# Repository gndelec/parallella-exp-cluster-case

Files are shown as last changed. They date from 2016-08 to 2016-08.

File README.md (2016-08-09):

# Parallella Experimental Cluster Case Kit

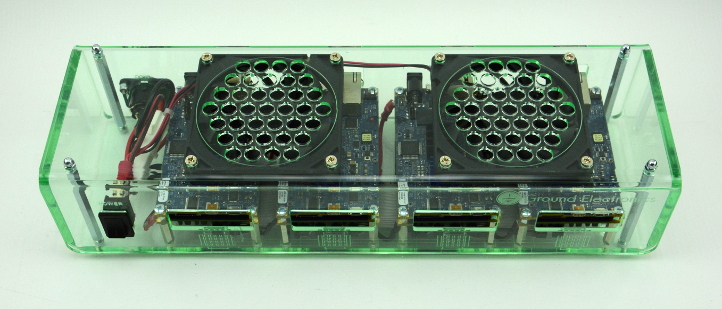
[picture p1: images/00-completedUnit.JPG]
A completed PACK-02 case


The PACK-02 kit is a simple but elegant case based on the "[sick of beige](http://dangerousprototypes.com/docs/Sick_of_Beige_basic_case_v1)" design and is intended for experimentation with the Parallella platform, along with multiple Porcupine breakout boards and eLink cables. It can be bought from [Ground Electronics](http://groundelectronics.com).

## Repository contents

The case design is provided in the following formats:

* Inkscape SVG (source)
* PDF
* DXF

The top cover is laser cut from 3mm glass look acrylic.
The base is laser cut from 5mm glass look acrylic.

## Bill of materials

In addition to the acrylic parts the PACK-02 kit contains:

| Qty | Item |
| --- | --- |
|  2  | 80mm  slimline fan |
|  1  | Rectangular rocker switch |
|  1  | Panel mount XLR socket |
|  4  | M3 x 60mm steel hex standoffs, M-F  |
|  16 | M3 x 20mm  steel hex standoffs, F-F |
|  16 | M3 x 5mm steel hex standoffs, M-F |
|  16 | M3 x 5mm steel machine screw |
|  4  | M3 x 8mm steel machine screw |
|  16 | M3 x 12mm nylon machine screw |
|  2  | M3 x 10mm countersunk steel machine screw |
|  2  | M3 nyloc nut |
|  8  | M5 x 12mm self tapping steel screw  |
|  4  | M3 dome nut |
|  4  | Self-adhesive rubber bumper |
|  1  | Small cable tie |
|  3  | Red jumper wire with ring terminals |
|  3  | Black jumper wire with ring terminals |
|  1  | Two-pin power connector with flying leads |
|  14 | M3 washer |
|  3  | Short ribbon cable w/30 pin connectors |
|  3  | Long ribbon cable w/30 pin connectors |
|  1  | High quality 5V, 8A power supply |

This kit is intended for between 2-4 Parallella boards, as well as Porcupine breakout boards (not included in the kit):

| Qty | Item |
| --- | --- |
| 2-4 | Parallella board |
| 2-4 | Porcupine breakout board |

## Assembly

Completed PACK-02

1 Remove the protective plastic from the acrylic panels.The top come pre-assembled with fans, switch and XLR socket in place.

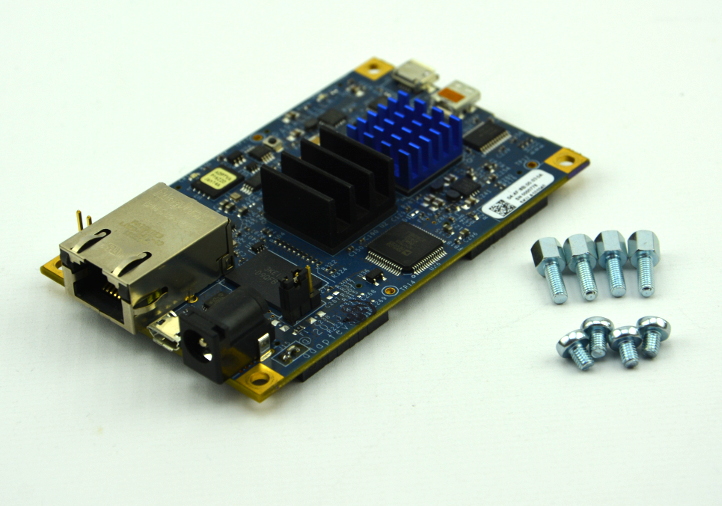
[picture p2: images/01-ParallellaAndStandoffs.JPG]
Parallella and standoffs


2 Start with a Parallella, 4x M3x5mm standoffs and 4x M3x5mm machine screws.

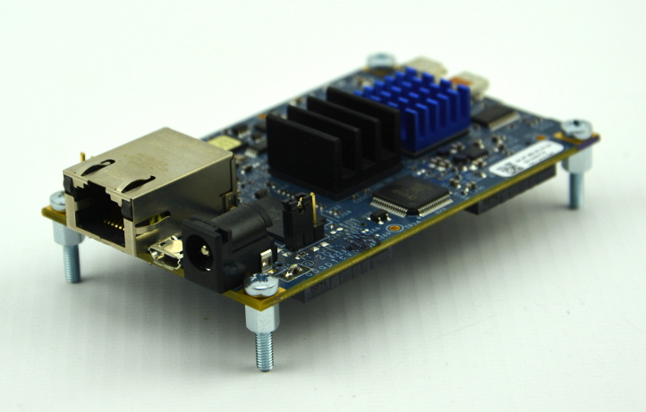
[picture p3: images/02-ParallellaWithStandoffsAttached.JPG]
Adding standoffs


3 Add the standoffs and screws as shown, and repeat for all Parallellas.

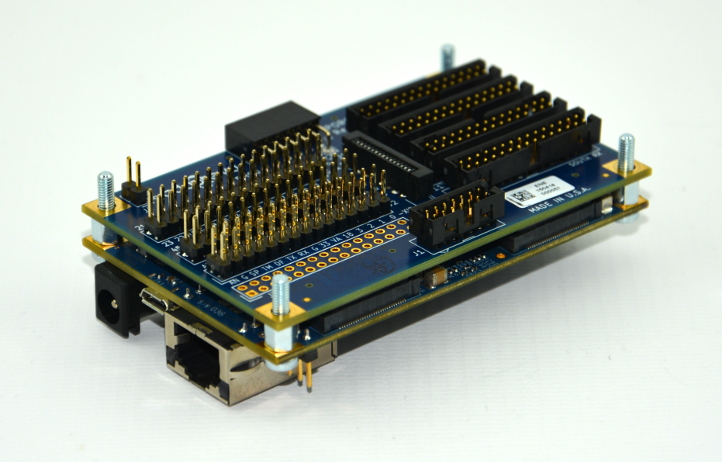
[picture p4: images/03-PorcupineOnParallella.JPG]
Adding Porcupine


4 Add the Porcupine breakout board, taking care that it is correctly oriented, and the high-density connectors are aligned before pushing together. Repeat for all Parallellas.

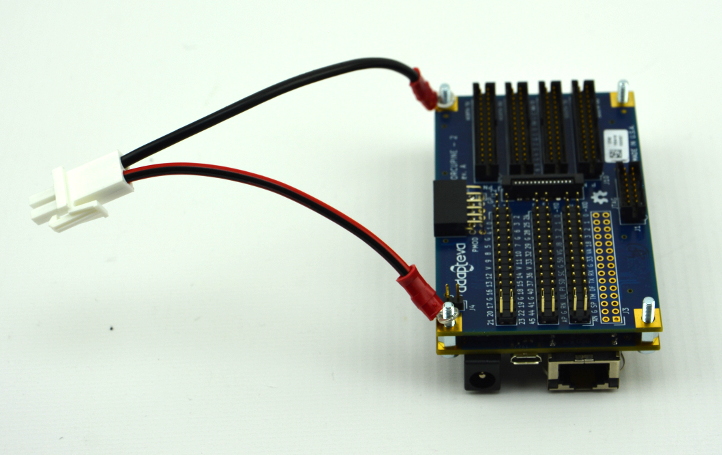
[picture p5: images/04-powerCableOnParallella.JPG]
Adding power cable


5 Add the main power cable to the first Parallella.

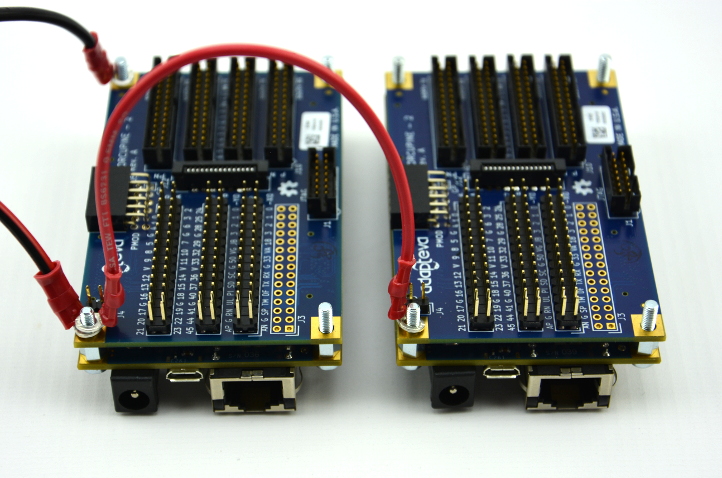
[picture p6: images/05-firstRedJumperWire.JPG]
Adding red jumper wire


6 Add the first red jumper wire as shown, between two Parallella boards. Take care to add to the correct threaded posts.

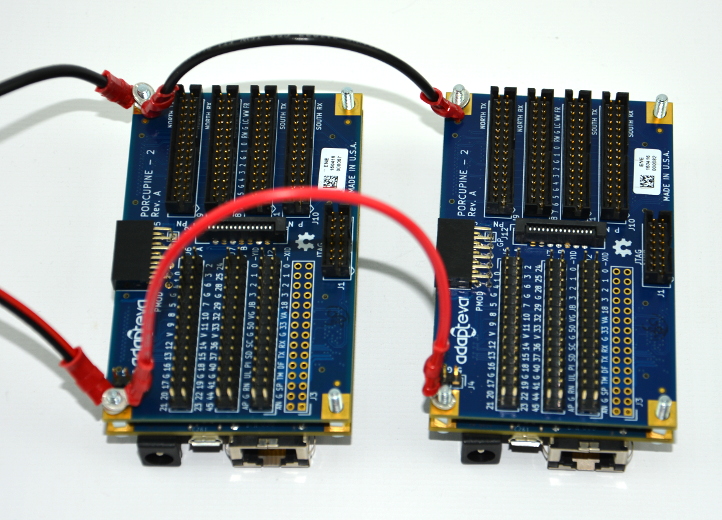
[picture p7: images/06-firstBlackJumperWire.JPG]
Adding black jumper wire


7 Add the first black jumper wire as shown, again taking care that to add it to the correct threaded posts.

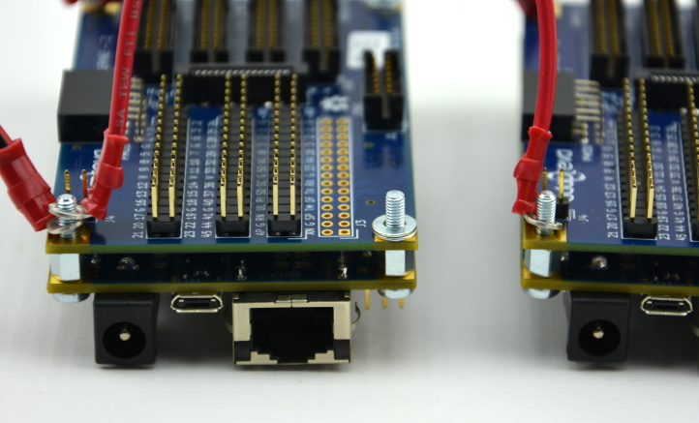
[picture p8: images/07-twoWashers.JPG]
Adding M3 washers


8 Add 4x M3 washers to the first Parallella, 2 to each unoccupied post, to match up with those occupied by the ring terminals.

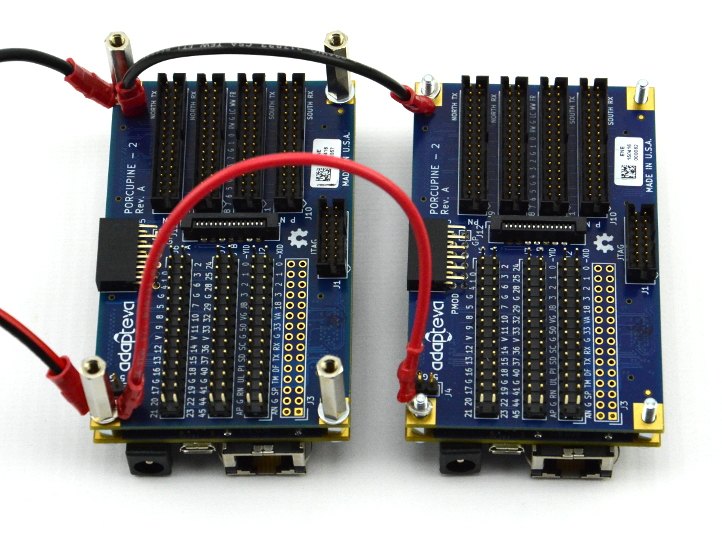
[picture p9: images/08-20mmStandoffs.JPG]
Adding M3x20mm standoffs


9 Add 4x M3x20mm standoffs to the first Parallella. Take care to note the orientation of the ring terminals, and that each standoff is sufficiently tight.

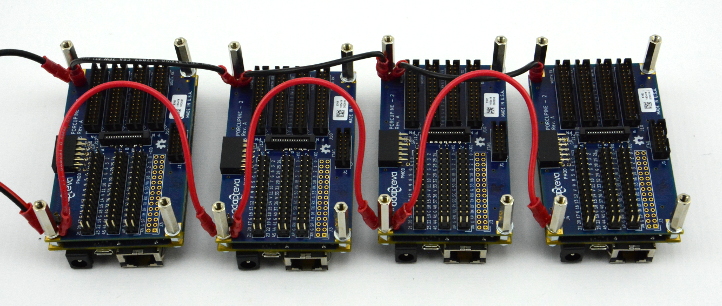
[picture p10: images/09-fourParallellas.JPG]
Repeat for other Parallellas


10 Repeat the last four steps until you have all of your Parallellas connected. Note that the last one only requires 1x M3 washer per unoccupied threaded post, since there is only one ring terminal on each occupied one.

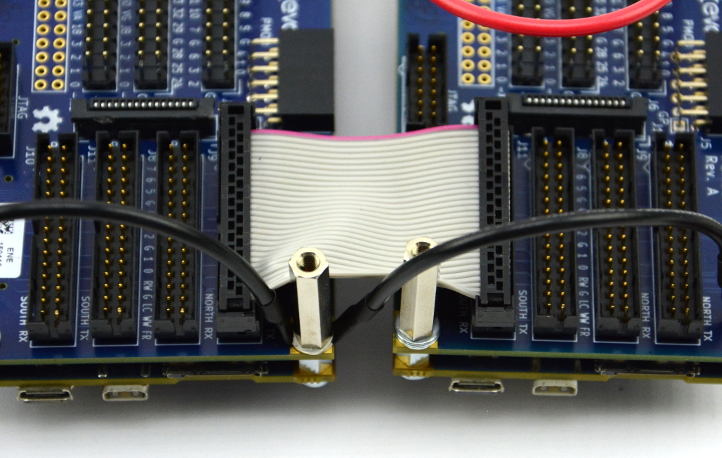
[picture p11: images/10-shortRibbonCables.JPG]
Adding short ribbon cables


11 Add the short ribbon cables between the Parallellas as shown, taking care when adding them to the Porcupine boards. Note that these cables must be inserted the correct way around, due to a locating tab.

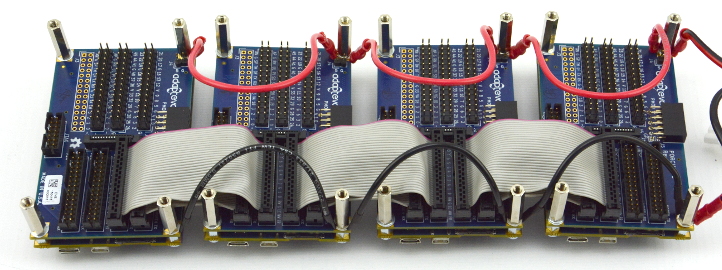
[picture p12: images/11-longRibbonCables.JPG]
Adding long ribbon cables


12 Add the long ribbon cables as shown, again taking care when pushing them in the Porcupine boards.

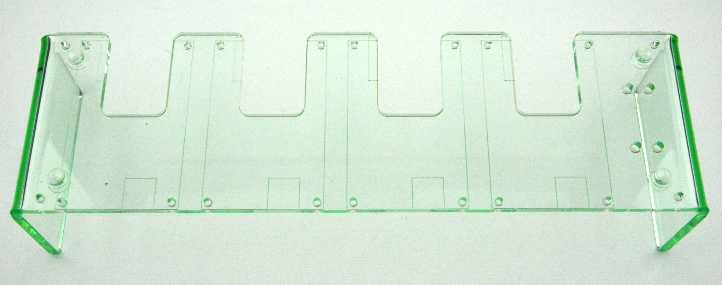
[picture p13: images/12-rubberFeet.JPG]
Adding the adhesive feet to the base


13 Turning attention to the base acrylic, add the 4x self-adheisve rubber bumpers, using the etched circles for alignment.

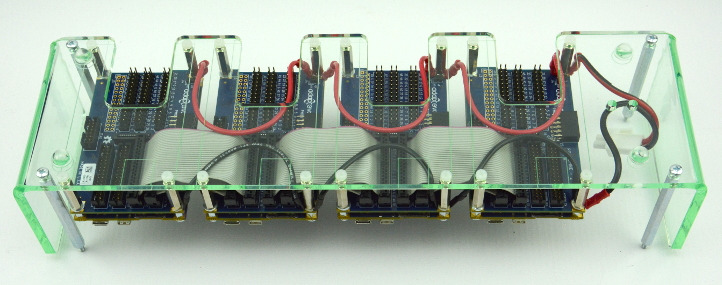
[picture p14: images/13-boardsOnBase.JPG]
Adding Parallellas to base


14 Add the Parallellas to the base, using 4x M3x12mm nylon machine screws per Parallella. Ensure that the boards are mounted as shown, with the base cutouts underneath the jumper pin headers.

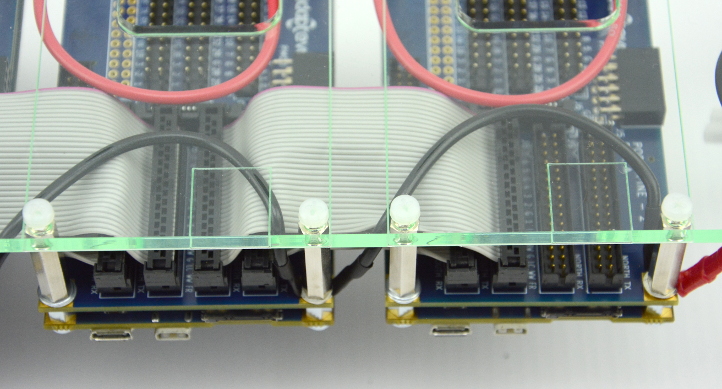
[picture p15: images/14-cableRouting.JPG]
Cable routing


15 Take care to ensure that the cables are routed as shown, all inside the 20mm steel standoffs.

16 Use the small cable tie to secure the main power leads to the base acrylic.

17 Add the 4x M3 x 60mm standoffs to the base, one in each corner, using 4x M3 x 8mm machine screws.

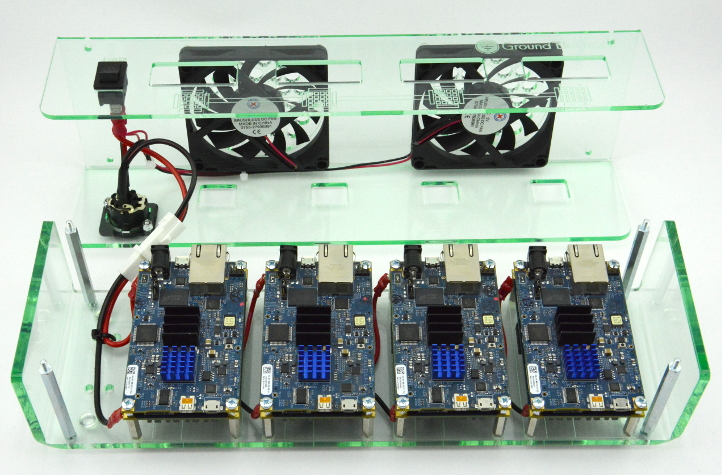
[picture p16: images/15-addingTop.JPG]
Adding top cover acrylic


18 Add the final acrylic top layer, first connecting the 2-pin power connectors.

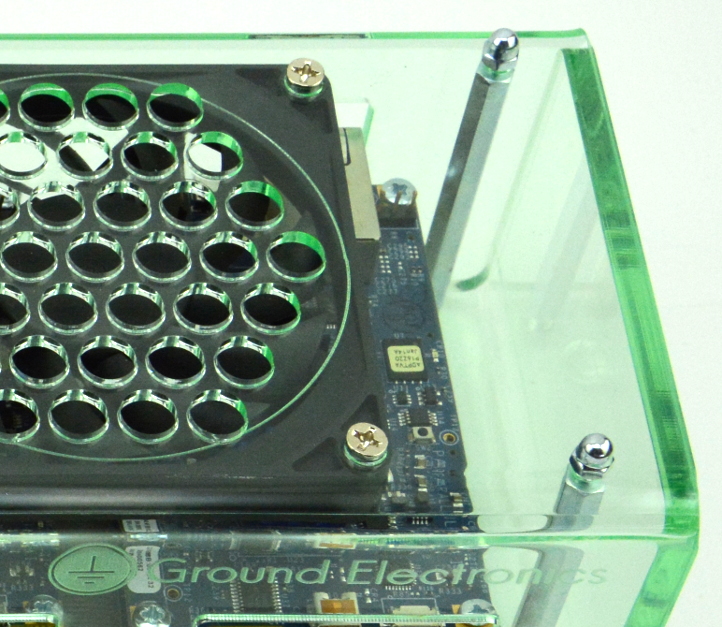
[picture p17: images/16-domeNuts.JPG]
Adding M3 dome nuts


17 Add the four M3 dome nuts.

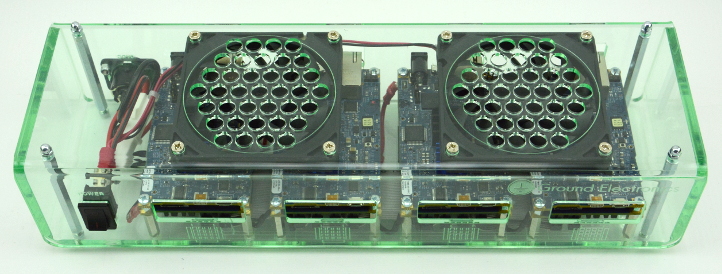
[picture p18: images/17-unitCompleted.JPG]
Unit completed!


18 The unit is assembled and ready for SD cards, the power supply to be connected and first boot!

## Changelog

| Version | Date | Summary |
|---|---|---|
| 1.0 | 09/08/16 | Initial version. |

## Licence

Parallella Experimental Cluster Case Kit copyright 2016, [AB Open Ltd](http://abopen.com).

<br />This work is licensed under a <a rel="license" href="http://creativecommons.org/licenses/by/4.0/">Creative Commons Attribution 4.0 International License</a>.

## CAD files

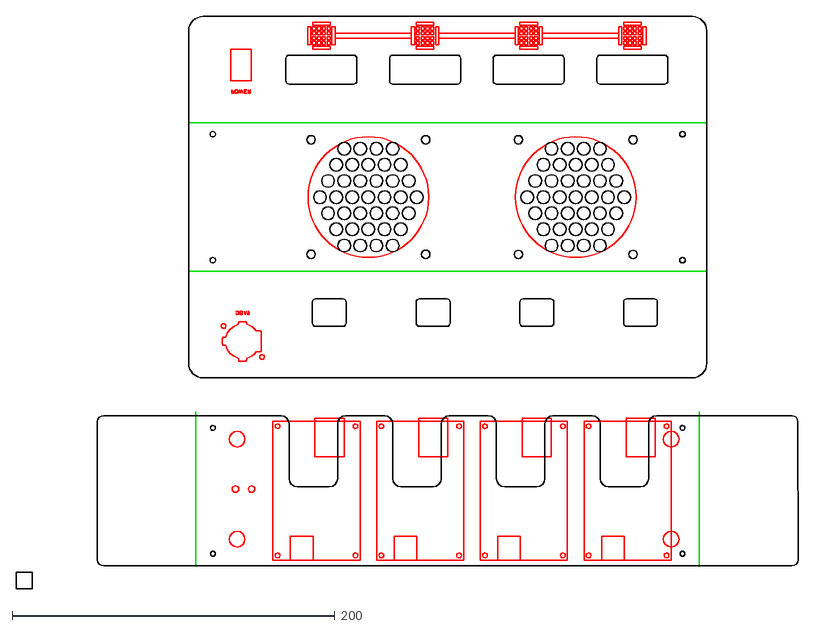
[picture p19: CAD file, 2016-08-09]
PACK-02-SHARE.dxf
484.6 x 354.6

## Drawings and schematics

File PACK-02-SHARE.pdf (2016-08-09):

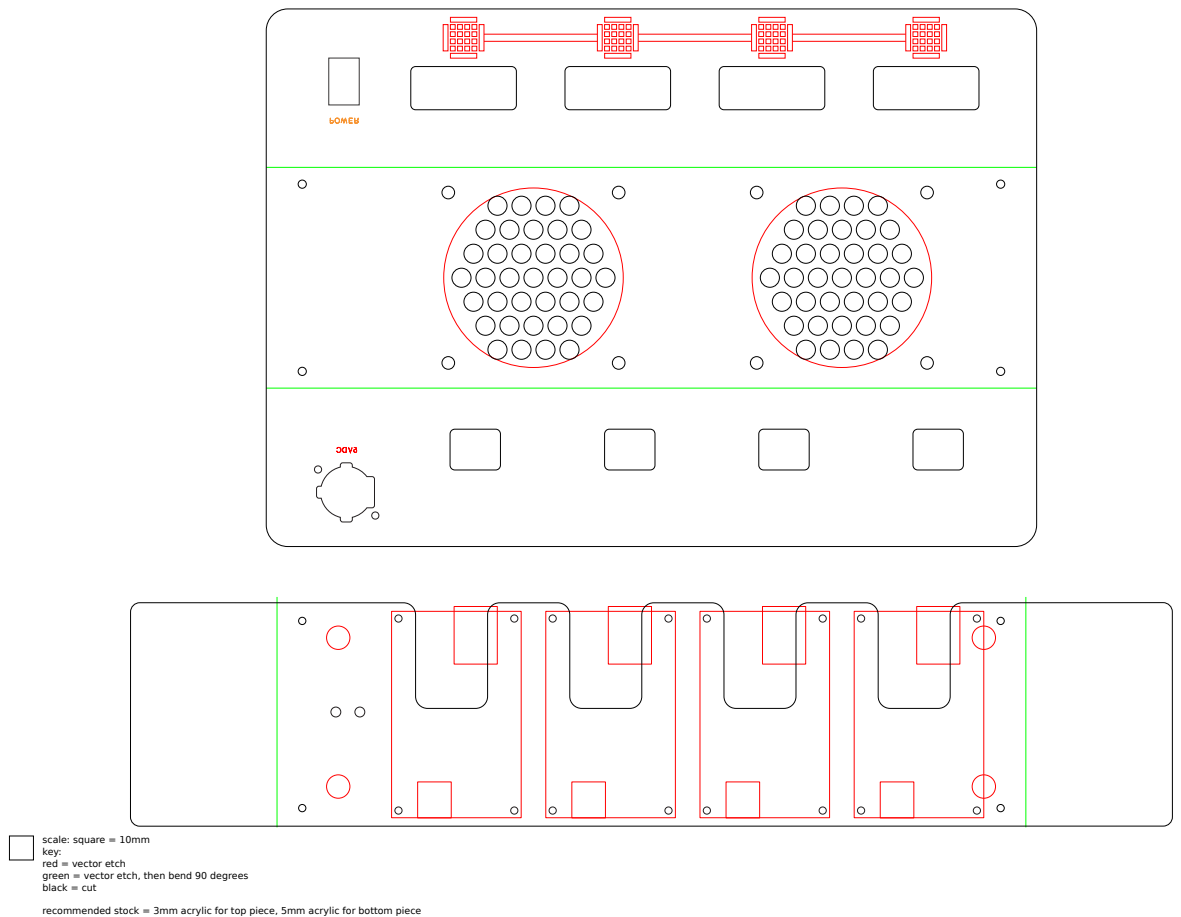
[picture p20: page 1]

scale: square = 10mm
key:
red = vector etch
green = vector etch, then bend 90 degrees
black = cut

recommended stock = 3mm acrylic for top piece, 5mm acrylic for bottom piece
